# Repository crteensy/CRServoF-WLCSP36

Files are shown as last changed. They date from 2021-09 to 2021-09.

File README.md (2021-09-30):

# CRServoF-WLCSP36
CRSF to Servo PWM converter, using an STM32F051 in WLCSP-36

This is a different take on https://github.com/CapnBry/CRServoF, but with major differences - so no fork.

## Purpose and features
Many modern RC receivers have serial output and a number of different serial protocols. A popular one is Crossfire (or CSRF). However, in anything other than multicopters that need a flight controller, these receivers are not very useful because they don't have per-channel PWM output for servos and ESCs.

Theses RC systems also feature telemetry to get data about battery state and many other things on the ground during flight. There are a number of serial protocols for attaching sensors to a receiver for anything that the receiver can't measure itself.

Features:
- STM32F051 in WLCSP-36 *
- CRSF compatible header to attach a receiver to
- 6 Servo PWM outputs
- extra UART header for sensor communication
- Supply for external sensors, either 3V3 or 5V (solder jumper)
- VBat sensing input to an ADC channel, with an on-board divider and filter cap
- LEDs on BEC and 3V3 rails
- SWD header

It is powered by an external BEC (usually the ESC should bring one). There is no regulator on board that will handle anything above 5V. Of course it can run off a 1S LiIon, LiPo or similar battery.

\*) You might ask why I used this package. It's simple: I didn't have any other at hand, and couldn't order any similar STM32 in a more friendly package. It can still be soldered at home, though!

## Layout

The layout is simple and doesn't require special PCB fabrication technology:
- min track width / clearance: 0.1 mm
- standard vias, 0.2 mm drill / 0.5 mm outer diameter, no tenting or similar extras
- 4 layers
- single sided assembly, 0402 or larger passives

In order to route signals that do not come from pins along the perimeter, multiple pins are shorted in order to reach the perimeter. Only one of these pins may drive it at any given time.

MCU Pinout and extra pins used to route the design:

| Function | Pin (GPIO) | Extra Pins (GPIOs) | Comment
|---|---|---|---|
| NRST | D5 | C6 (PC15) |
| BOOT0 | B4 | B5 (PF0), A6 (PC13) | 10k Pull-down
| PWM 1 | A2 (PA15) | | TIM2_CH1, 1k series resistor (also boot loader UART Rx)
| PWM 2 | A3 (PB4) | |  TIM3_CH1, 1k series resistor
| PWM 3 | B3 (PB3) | A4 (PB7) | TIM2_CH2, 1k series resistor
| PWM 4 | F3 (PB0) | | TIM3_CH3, 1k series resistor
| PWM 5 | D1 (PA9) | | TIM1_CH2, 1k series resistor
| PWM 6 | F2 (PB1) | | TIM3_CH4, 1k series resistor
| SWCLK | B2 (PA14) | A1 (PA12) | (also boot loader Tx, 1k series resistor)
| SWDIO | B1 (PA13) | |
| UART1 Tx | C4 (PB6) | C5 (PF1), B6 (PC14)  | 1k series resistor
| UART1 Rx | C1 (PA10) | |
| UART2 Tx | E4 (PA2) | F4 (PA7) | CRSF header, 1k series resistor
| UART2 Rx | F5 (PA3) | | CRSF header
| ADC | F6 (PA0) | | ADC_IN0, 10k/1k divider and filter cap
| VDD,VDDA | A5, E1, E5 | E6 (PB5) | supply
| VSS, VSSA | F1, D6 | | GND

The boot loader UART (UART2) on PA14/PA15 can be accessed through a dedicated set of pads on the bottom. One of them (UART2_Tx) is shared with a servo output, but that doesn't hurt during programming.

If the battery voltage (to be measured with the ADC) is accidentally connected to a servo output, this will probably not cause damage because all PWM outputs have a 1k series resistor. Unless it's connected in reverse. That would be bad, even on the VBat header.

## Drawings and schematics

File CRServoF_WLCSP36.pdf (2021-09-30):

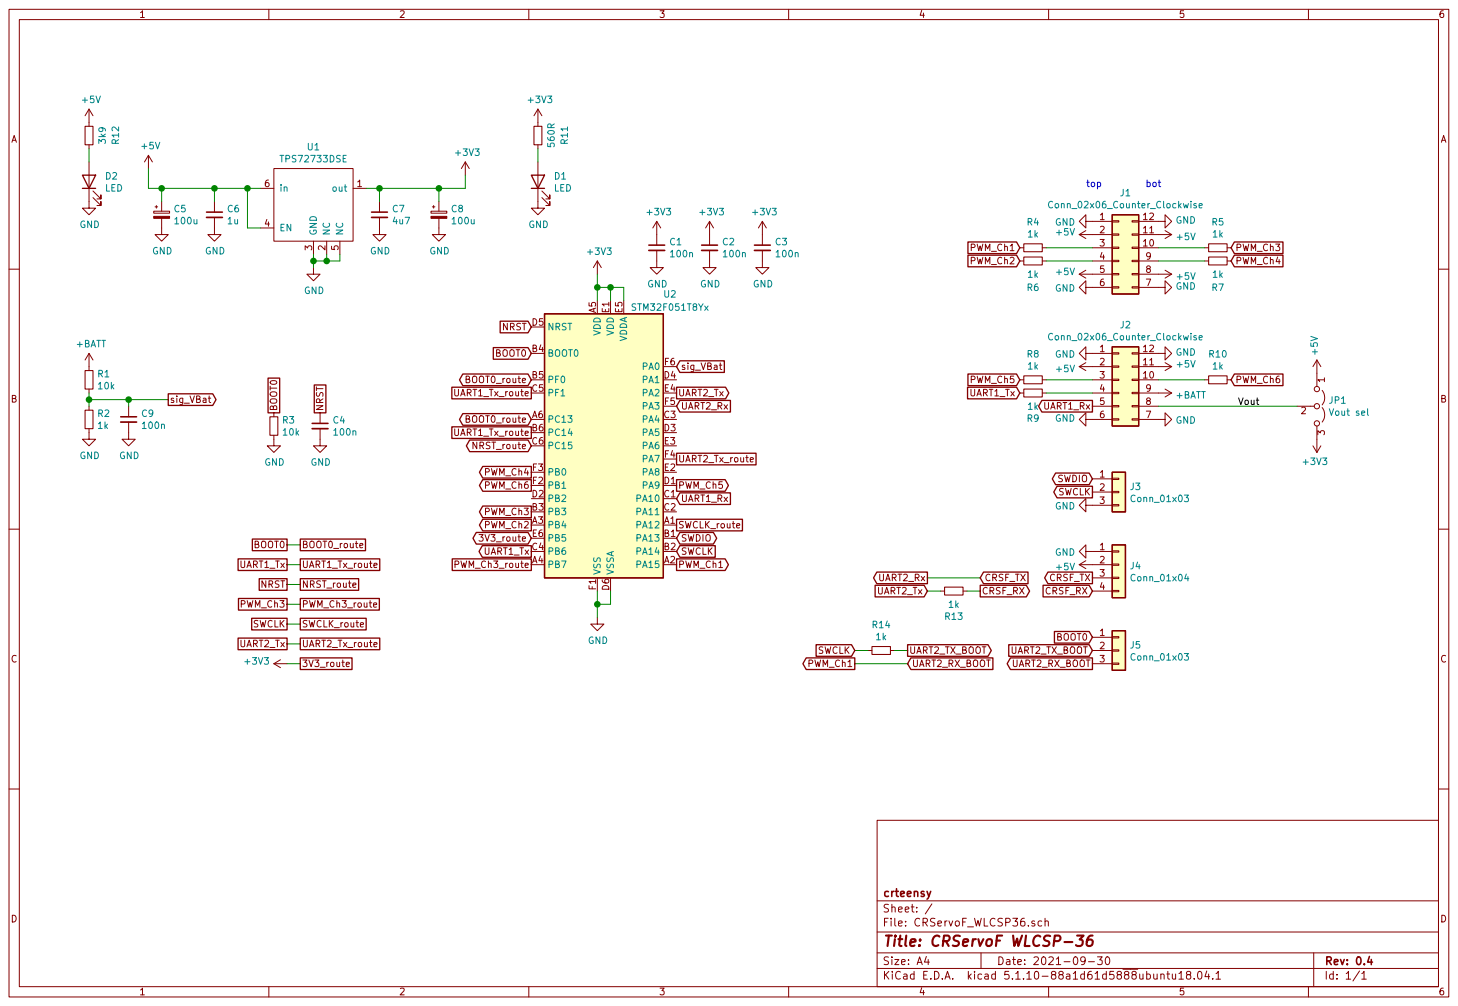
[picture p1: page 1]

File: CRServoF_WLCSP36.sch Sheet: / crteensy

Id: 1/1 Title: CRServoF WLCSP-36

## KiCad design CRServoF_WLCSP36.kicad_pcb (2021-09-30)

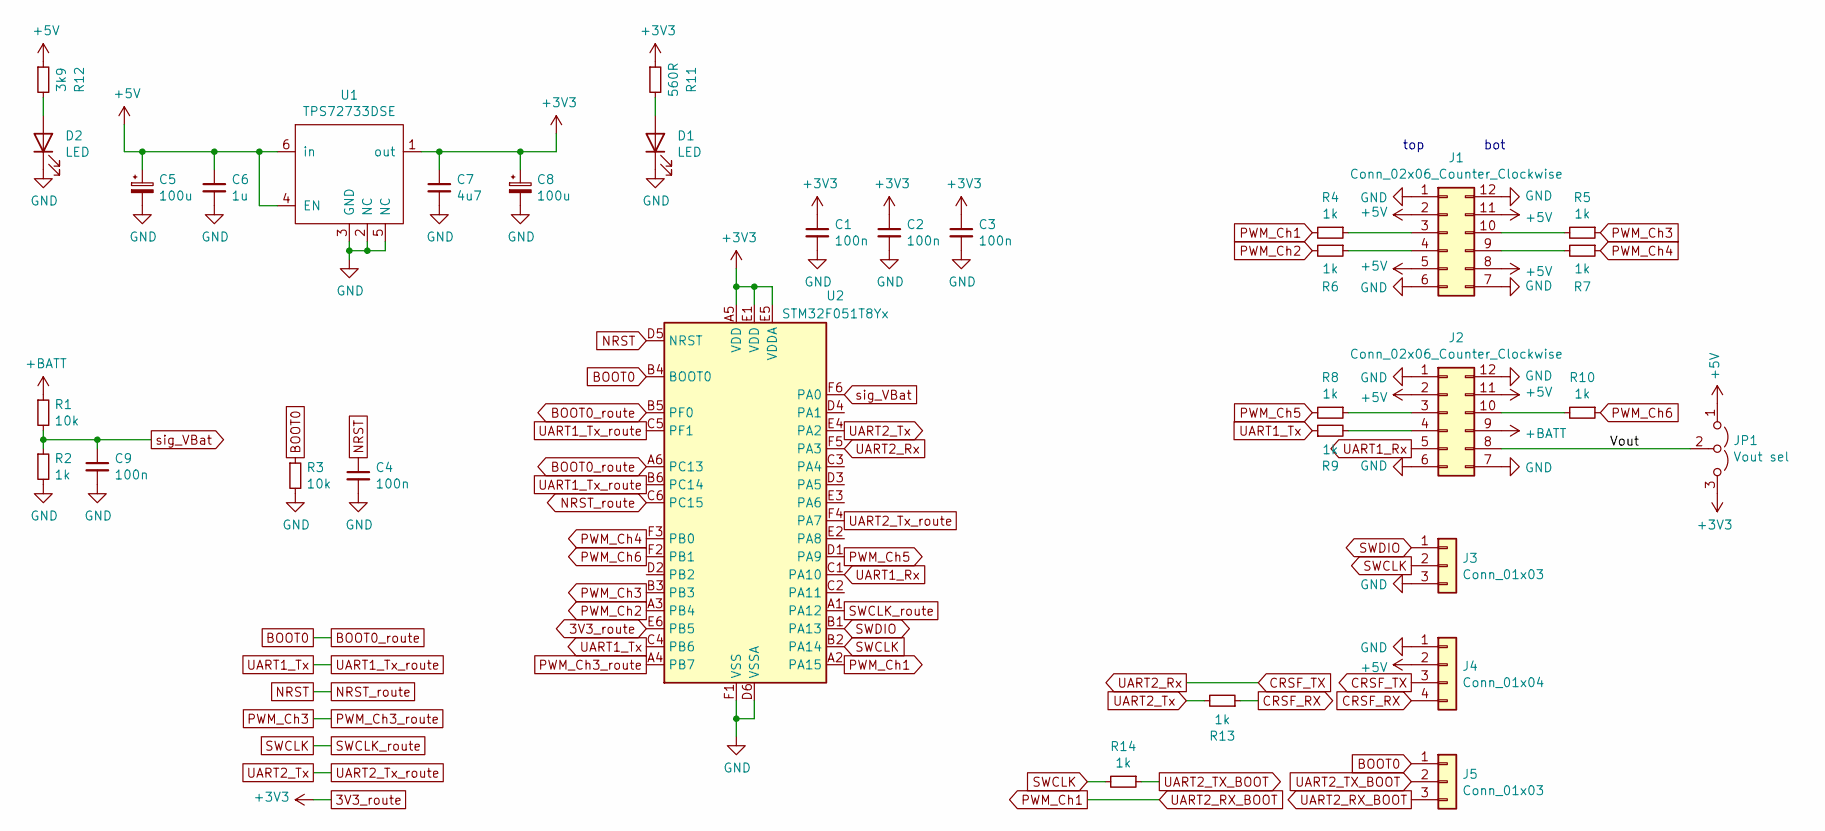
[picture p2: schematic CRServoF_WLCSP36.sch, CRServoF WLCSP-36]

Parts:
C1, C2, C3, C4, C9: 100n; C_0402_1005Metric
C5, C8: 100u; CP_EIA-3216-18_Kemet-A
C6: 1u; C_0603_1608Metric
C7: 4u7; C_0603_1608Metric
D1, D2: LED; LED_0402_1005Metric
J1, J2: Conn_02x06_Counter_Clockwise; BoardEdge_Servo_4
J3, J5: Conn_01x03; BoardEdge_Servo_1
J4: Conn_01x04; PinHeader_1x04_P2.54mm_Vertical
JP1: Vout sel; SolderJumper-3_P1.3mm_Open_RoundedPad1.0x1.5mm
R1, R3: 10k; R_0402_1005Metric
R2, R4, R5, R6, R7, R8, R9, R10, R13, R14: 1k; R_0402_1005Metric
R11: 560R; R_0402_1005Metric
R12: 3k9; R_0402_1005Metric
U1: TPS72733DSE; WSON-6_1.5x1.5mm_P0.5mm
U2: STM32F051T8Yx; ST_WLCSP-36_Die440

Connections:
3V3_route: C1.1, C2.1, C3.1, C7.1, C8.1, JP1.3 (B), R11.1, U1.1 (out), U2.A5 (VDD), U2.E1 (VDD), U2.E5 (VDDA), U2.E6 (PB5)
+5V: C5.1, C6.1, J1.2, J1.5, J1.8, J1.11, J2.2, J2.11, J4.2, JP1.1 (A), R12.1, U1.4 (EN), U1.6 (in)
+BATT: J2.9, R1.1
/Vout: J2.8, JP1.2 (C)
BOOT0: J5.1, R3.1, U2.A6 (PC13), U2.B4 (BOOT0), U2.B5 (PF0)
CRSF_RX: J4.4, R13.1
CRSF_TX: J4.3, U2.F5 (PA3)
GND: C1.2, C2.2, C3.2, C4.2, C5.2, C6.2, C7.2, C8.2, C9.2, D1.1 (K), D2.1 (K), J1.1, J1.6, J1.7, J1.12, J2.1, J2.6, J2.7, J2.12, J3.3, J4.1, R2.2, R3.2, U1.2 (NC), U1.3 (GND), U1.5 (NC), U2.D6 (VSSA), U2.F1 (VSS)
NRST: C4.1, U2.C6 (PC15), U2.D5 (NRST)
unnamed: D1.2 (A), R11.2
unnamed: D2.2 (A), R12.2
unnamed: J1.3, R4.1
unnamed: J1.4, R6.1
unnamed: J1.9, R7.2
unnamed: J1.10, R5.2
unnamed: J2.3, R8.1
unnamed: J2.4, R9.2
unnamed: J2.10, R10.2
PWM_Ch1: J5.3, R4.2, U2.A2 (PA15)
PWM_Ch2: R6.2, U2.A3 (PB4)
PWM_Ch3: R5.1, U2.A4 (PB7), U2.B3
PWM_Ch4: R7.1, U2.F3 (PB0)
PWM_Ch5: R8.2, U2.D1 (PA9)
PWM_Ch6: R10.1, U2.F2 (PB1)
SWCLK: J3.2, R14.2, U2.A1 (PA12), U2.B2 (PA14)
SWDIO: J3.1, U2.B1 (PA13)
UART1_Rx: J2.5, U2.C1 (PA10)
UART1_Tx: R9.1, U2.B6 (PC14), U2.C4 (PB6), U2.C5 (PF1)
UART2_TX_BOOT: J5.2, R14.1
UART2_Tx: R13.2, U2.E4 (PA2), U2.F4 (PA7)
sig_VBat: C9.1, R1.2, R2.1, U2.F6 (PA0)

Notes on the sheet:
top
bot

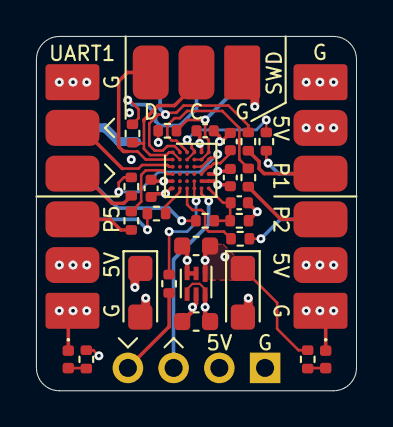
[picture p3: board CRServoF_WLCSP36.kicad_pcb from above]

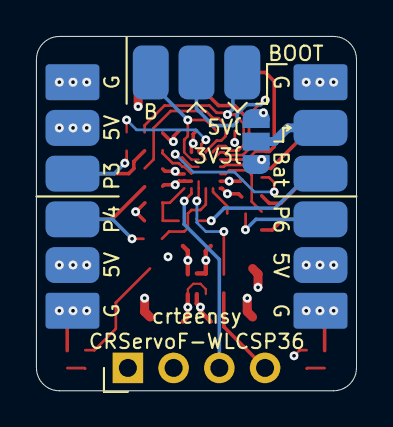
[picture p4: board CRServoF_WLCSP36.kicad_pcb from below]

Board: 4 copper layers, 17.8 x 19.7 mm, 33 parts (3 on the bottom side), 31 nets.

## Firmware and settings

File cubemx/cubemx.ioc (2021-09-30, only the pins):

Mcu.UserName=STM32F051T8Yx
PA0.Signal=ADC_IN0
PA10.Signal=USART1_RX
PA12.GPIO_Label=route
PA12.Signal=GPIO_Analog
PA13.Signal=SYS_SWDIO
PA14.Signal=SYS_SWCLK
PA15.Signal=S_TIM2_CH1_ETR
PA2.Signal=USART2_TX
PA3.Signal=USART2_RX
PA7.GPIO_Label=route
PA7.Signal=GPIO_Analog
PA9.Signal=S_TIM1_CH2
PB0.Signal=S_TIM3_CH3
PB1.Signal=S_TIM3_CH4
PB3.Signal=S_TIM2_CH2
PB4.Signal=S_TIM3_CH1
PB5.GPIO_Label=route
PB5.Signal=GPIO_Analog
PB6.Signal=USART1_TX
PB7.GPIO_Label=route
PB7.Signal=GPIO_Analog
PC13.GPIO_Label=route
PC13.Signal=GPIO_Analog
PC14-OSC32_IN.GPIO_Label=route
PC14-OSC32_IN.Signal=GPIO_Analog
PC15-OSC32_OUT.GPIO_Label=route
PC15-OSC32_OUT.Signal=GPIO_Analog
PF0-OSC_IN.GPIO_Label=route
PF0-OSC_IN.Signal=GPIO_Analog
PF1-OSC_OUT.GPIO_Label=route
PF1-OSC_OUT.Signal=GPIO_Analog

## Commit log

2021-09-30 add design files
    [CRServoF_WLCSP36.kicad_pcb, CRServoF_WLCSP36.sch]
2021-09-30 update schematic and silk screen
    [CRServoF_WLCSP36.kicad_pcb, CRServoF_WLCSP36.sch]
2021-09-30 Update README.md
    fix PWM output labels
